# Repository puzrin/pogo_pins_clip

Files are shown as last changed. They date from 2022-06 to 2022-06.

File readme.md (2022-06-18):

Pogo pins clip <!-- omit in toc -->
==============

> Clips for SWD programming/debugging. Easy to modify for your needs.

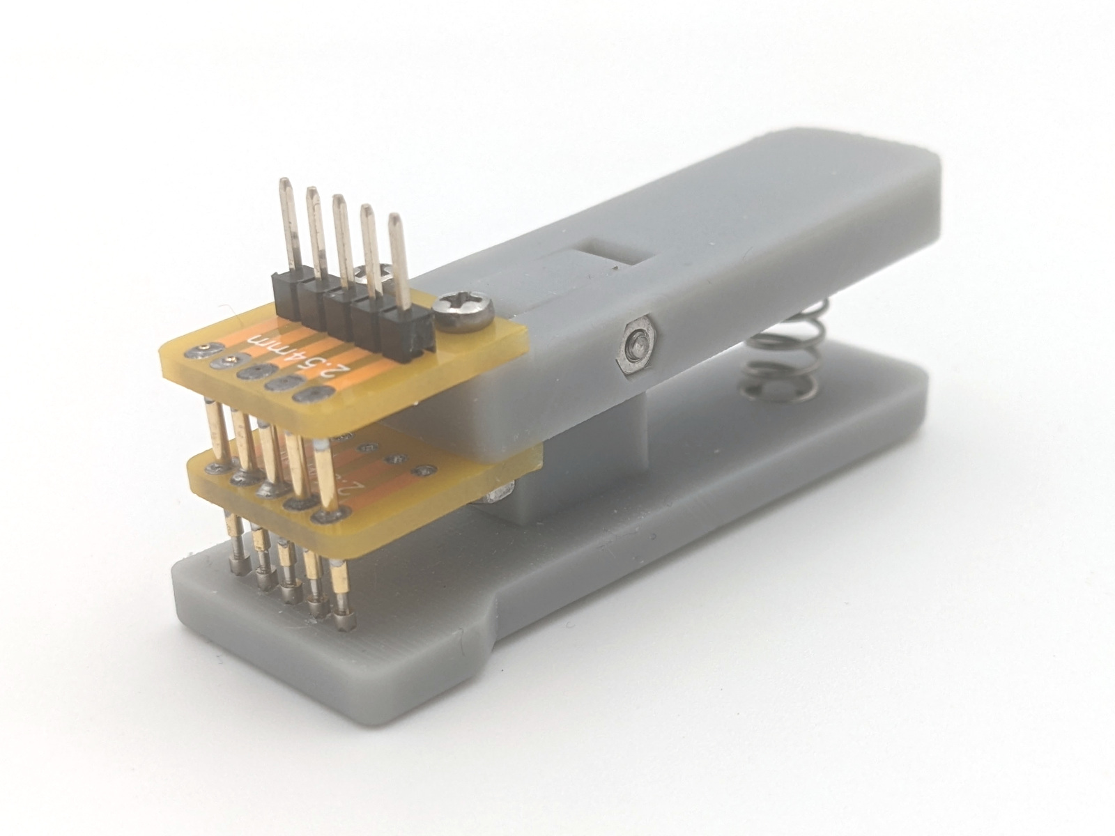
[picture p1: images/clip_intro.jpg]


- [Components](#components)
- [Assembly](#assembly)
- [Alternatives](#alternatives)

## Components

&nbsp; | Name | Comment
-----|-------------|--------
1 | [PCB](https://oshwlab.com/puzrin/pogo-pins-clip) | Modify if needed
2 | Pogo pin [P50-F1](https://www.aliexpress.com/item/1005003501730262.html)| For 1.27mm step. Alt: [P50-LM2](https://www.aliexpress.com/item/1047975817.html).
3 | Pogo pin [P75-E2](https://www.aliexpress.com/item/32874022638.html)| For 2.54mm step. Alt: [P75-E2](https://www.aliexpress.com/item/32874022638.html), [P75-LM2](https://www.aliexpress.com/item/1047975817.html).
4 | [Spring](https://www.aliexpress.com/item/4001178729297.html) | 0.6\*6\*20mm or 0.7\*6\*15mm should be ok.
5 | [2.54mm pins](https://www.aliexpress.com/item/32993182990.html) |
6 | [M2 12mm screws](https://www.aliexpress.com/item/33012059322.html) | DIN 7985 / ISO 7045. PCB mount.
7 | [M2 14mm screws](https://www.aliexpress.com/item/33012059322.html) | DIN 7985 / ISO 7045. Join plastic parts.
8 | [M2 spring lock washes](https://www.aliexpress.com/item/4000222556028.html) |
9 | [M2 nuts](https://www.aliexpress.com/item/4000226223259.html) |
10 | [0.9mm needles](https://www.aliexpress.com/item/33011464623.html) | Only for TC2030 clip. Stainless steel wire should be ok too.
11 | 3d-printed clip parts | See [3dprint folder](./3dprint/)

Order plastic parts at jlcpcb, with the PCB-s: https://cart.jlcpcb.com/quote?businessType=tdpGoodsFile. Select SLA process and LEDE 6060 material.

## Assembly

First, mount PCB-s and solder pogo pins. Put top PCB on the table to align all
pins and solder from the bottom side.

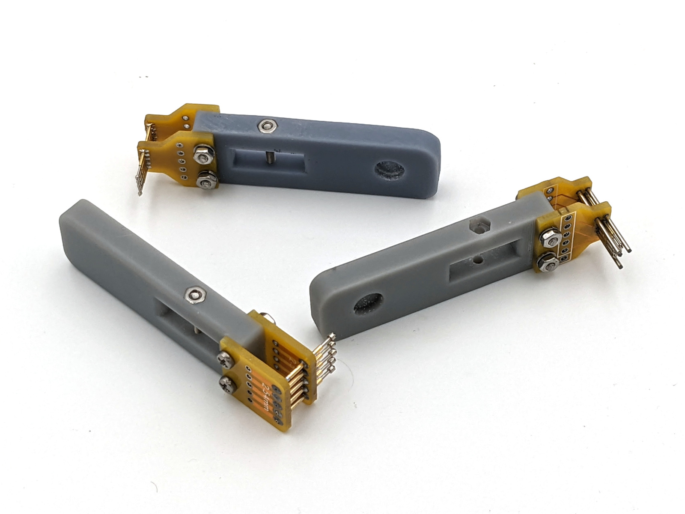
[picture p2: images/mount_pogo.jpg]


Then detach PCB-s, mount connector & wash flux off.

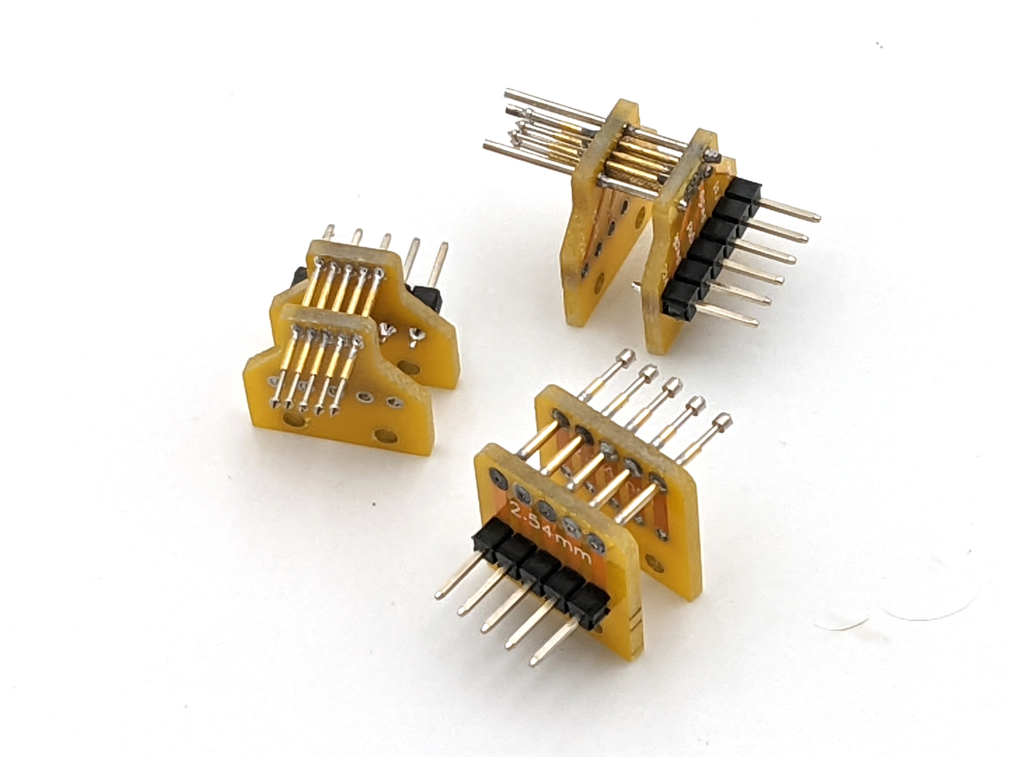
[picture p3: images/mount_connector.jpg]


Now assemble everything and install spring.

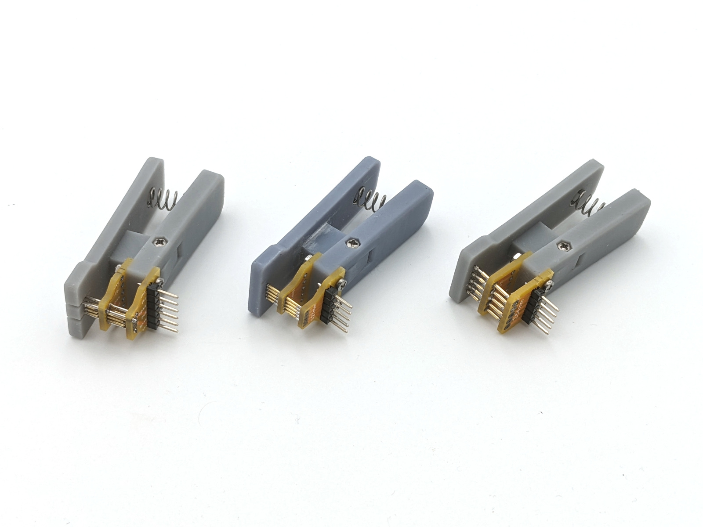
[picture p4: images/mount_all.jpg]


## Alternatives

You can order alternate clips at AliExpress, or use those as base for custom
PCB-s.

- [2.54mm](https://www.aliexpress.com/item/32827181680.html) clip.
- [1.27mm](https://www.aliexpress.com/item/32959606674.html) clip.

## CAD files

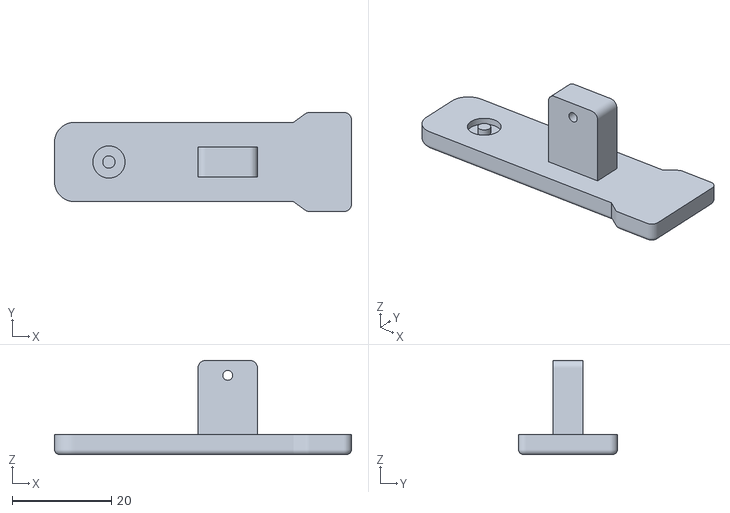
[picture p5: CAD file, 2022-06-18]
3dprint/clip_bottom.stl
60.0 x 20.0 x 19.0

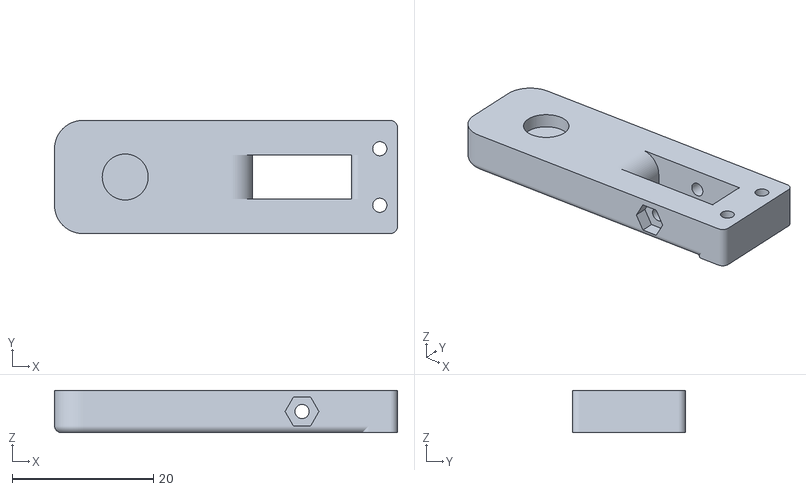
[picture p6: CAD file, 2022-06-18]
3dprint/clip_top.stl
48.5 x 16.0 x 6.00

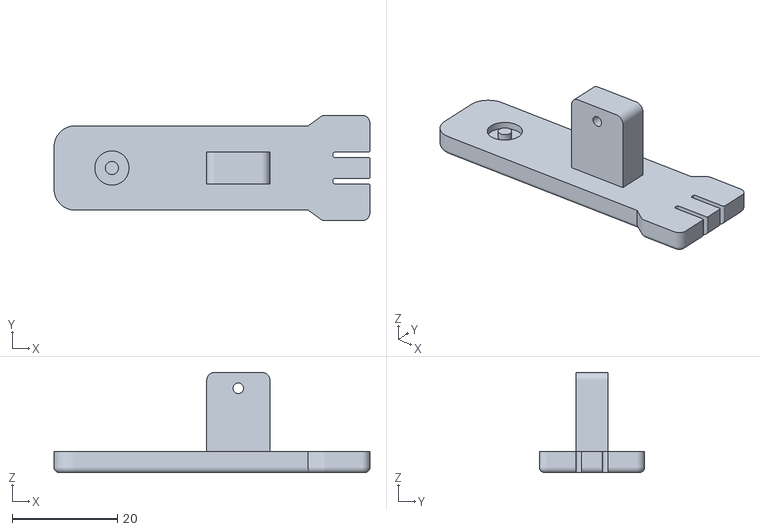
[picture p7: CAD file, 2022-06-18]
3dprint/clip_bottom_tc2030.stl
60.0 x 20.0 x 19.0

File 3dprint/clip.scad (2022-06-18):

use <utils.scad>

$fn = $preview ? 12 : 72;
e = 0.01;

// Space between details.
// SLA is more precise than FDM, 0.2mm shoudl be ok.
gap = 0.2;

module bottom() {
    h = 4;
    len = 60;
    w1 = 16;
    w2 = 20;
    l2 = 10;

    // long part
    difference () {
        translate_x(len/2) rcube([len, w1, h], r=4, rbottom=1);

        // spring holder
        translate([11, 0, h-1.3])
        difference() {
            cylinder(10, d=6.5);
            cylinder(30, d=2.5, center=true);
        }
    }

    // head
    translate_x(len)
    hull() {
        translate_x(-l2/2) rcube([l2, w2, h], r=1.5, rbottom=1);
        translate_x(-l2/2-14) rcube([2, 2, h], r=1.5, rbottom=1);
    }

    // bridge
    translate_x(35)
    difference() {
        translate([0, 6/2, 19/2]) rotate_x(90) rcube([12, 19, 6], r=1.5);
        translate_z(16) rotate_x(90) cylinder(10, d=2, center=true);
    }
}

module top() {
    h = 6;
    len = 48.5;
    w = 16;
    r1 = 5;
    r2 = 1.5;
    difference () {
        union() {
            translate_x(len/2) rcube([len, w, h], r=4, rbottom=1);
            translate_x(len-5/2) rcube([5, w, h], r=1);
        }

        // spring holder
        translate([10, 0, h-2]) cylinder(10, d=6.5);

        // PCB holes
        translate([len-2.5, 4, 0]) cylinder(100, d=2, center=true);
        translate([len-2.5, -4, 0]) cylinder(100, d=2, center=true);

        // bridge hole
        bhv = 14;
        translate([35, 0, 0]) {
            cube([bhv, 6+gap, 20], center=true);

            translate([bhv/2, (6+gap)/2, 0])
            rotate([90,0,0]) qfillet(6+gap, 1);

            translate([bhv/2, (6+gap)/2, 6])
            rotate([90,90,0]) qfillet(6+gap, 1);

            translate([-bhv/2, (6+gap)/2, 0])
            rotate([90,-90,0]) qfillet(6+gap, 1);

            translate([-bhv/2, (6+gap)/2, 6])
            rotate([90,180,0]) qfillet(6+gap, 3);
        }

        // bridge shaft
        translate([35, 0, h/2])
        rotate_x(90) cylinder(100, d=2, center=true);

        // bridge nuts
        translate([35, w/2+e, h/2])
        rotate_x(90) cylinder_outer(2, 4.15/2, 6);

        mirror([0, 1, 0])
        translate([35, w/2+e, h/2])
        rotate_x(90) cylinder_outer(2, 4.15/2, 6);

    }
}

module bottom_tc2030() {
    difference() {
        bottom();

        translate([60, 2+0.5, -e])
        rcube([14,1,20], center=true, r=0.3);
        translate([60, 3, 0]) rotate_z(90) qfillet(10, 0.3);
        translate([60, 2, 0]) rotate_z(180) qfillet(10, 0.3);

        mirror([0, 1, 0]) {
            translate([60, 2+0.5, -e])
            rcube([14,1,20], center=true, r=0.3);
            translate([60, 3, 0]) rotate_z(90) qfillet(10, 0.3);
            translate([60, 2, 0]) rotate_z(180) qfillet(10, 0.3);
        }
    }
}

if (!is_undef(mode) && mode == 1) top();
else if (!is_undef(mode) && mode == 2) bottom();
else if (!is_undef(mode) && mode == 3) bottom_tc2030();
else {
    bottom();
    translate([0, 25, 0]) top();
    translate([0, -25, 0]) top();
    translate([0, -50, 0]) bottom_tc2030();
}

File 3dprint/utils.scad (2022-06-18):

e = 0.01;
2e = 0.02;


module qfillet(h, r) {
    difference () {
        translate([-e, -e, 0]) cube([r+e, r+e, h]);
        translate([r, r, -e]) cylinder(h+2e, r = r);
    }
}

module torus(r1, r2, $fn = $fn) {
    rotate_extrude(convexity=2, $fn=$fn)
    difference() {
        translate([r1 - r2, 0, 0]) circle(r=r2, $fn=$fn);
        translate([-r2, 0, 0]) square(r2*2, true);
    }
}

module _hooled_toruses(x, y, r_xy, r_z) {
    translate([r_xy, r_xy, 0]) torus(r_xy, r_z);
    translate([x-r_xy, r_xy, 0]) torus(r_xy, r_z);
    translate([r_xy, y-r_xy, 0]) torus(r_xy, r_z);
    translate([x-r_xy, y-r_xy, 0]) torus(r_xy, r_z);
    
    translate([r_z, r_xy, 0]) rotate([-90, 0, 0]) cylinder(y-r_xy*2, r=r_z);
    translate([x-r_z, r_xy, 0]) rotate([-90, 0, 0]) cylinder(y-r_xy*2, r=r_z);
    translate([r_xy, r_z, 0]) rotate([0, 90, 0]) cylinder(x-r_xy*2, r=r_z);
    translate([r_xy, y-r_z, 0]) rotate([0, 90, 0]) cylinder(x-r_xy*2, r=r_z);
    
    translate([r_z, r_z, -r_z])
    rcube([x-r_z*2, y-r_z*2, r_z*2], r = r_xy-r_z, center = false);
}


module rcube(size = [10, 10, 10], center = true, r = 1, rtop = 0, rbottom = 0) {
    x = size[0]; y = size[1]; h = size[2];

    tx = center ? -x/2 : 0;
    ty = center ? -y/2 : 0;

    translate([tx, ty, 0]) {
        if (rtop == 0 && rbottom == 0) {
            translate([r, r, 0]) cylinder(h, r = r);
            translate([x-r, r, 0]) cylinder(h, r = r);
            translate([r, y-r, 0]) cylinder(h, r = r);
            translate([x-r, y-r, 0]) cylinder(h, r = r);
            translate([0, r, 0]) cube([x, y-r*2, h]);
            translate([r, 0, 0]) cube([x-r*2, y, h]);
        }
        if (rtop > 0 && rbottom == 0) {
            translate([0, 0, h-rtop]) _hooled_toruses(x, y, r, rtop);
            rcube([x, y, h-rtop], r = r, center = false);
        }
        if (rtop == 0 && rbottom > 0) {
            translate([0, 0, rbottom]) _hooled_toruses(x, y, r, rbottom);
            translate([0, 0, rbottom])
            rcube([x, y, h-rbottom], r = r, center = false);
        }
        if (rtop > 0 && rbottom > 0) {
            translate([0, 0, h-rtop]) _hooled_toruses(x, y, r, rtop);
            translate([0, 0, rbottom]) _hooled_toruses(x, y, r, rbottom);
            translate([0, 0, rbottom])
            rcube([x, y, h-rbottom-rtop], r = r, center = false);            
        }
    }
}

// skew takes an array of six angles:
// [ x:y, x:z, y:x, y:z, z:x, z:y ]
module skew(dims) {
    matrix = [
        [ 1, tan(dims[0]), tan(dims[1]), 0 ],
        [ tan(dims[2]), 1, tan(dims[3]), 0 ],
        [ tan(dims[4]), tan(dims[5]), 1, 0 ],
        [ 0, 0, 0, 1 ]
    ];
    multmatrix(matrix) children();
}


module cylinder_outer(height, radius, edges = 6) {
    fudge = 1/cos(180/edges);
    cylinder(h=height,r=radius*fudge,$fn=edges);
}


module rotate_x(angle) { rotate([angle, 0, 0]) children(); }
module rotate_y(angle) { rotate([0, angle, 0]) children(); }
module rotate_z(angle) { rotate([0, 0, angle]) children(); }

module translate_x(angle) { translate([angle, 0, 0]) children(); }
module translate_y(angle) { translate([0, angle, 0]) children(); }
module translate_z(angle) { translate([0, 0, angle]) children(); }
